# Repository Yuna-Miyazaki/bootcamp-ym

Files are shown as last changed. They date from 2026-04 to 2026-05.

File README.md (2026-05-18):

# 猫型ラジコンロボット
制作時にファイルを整理できていないため、動かない場合はバージョンが古い可能性有り。後々整えて上げ直す予定。
それと、まだ上がっていないものもあるので、上げる。

## 成果物
https://github.com/user-attachments/assets/66224314-2f7b-4e0d-81c6-8145114de999

## 使用モジュール
- M5stack capsule
- Feetech sts3215 ×3
- Feetech FE-URT-1
- M5stack UnitV2 Aiカメラ

## cat_robot
M5stack capsuleに書き込んだプログラム

### 役割
- カメラによる物体認識
- モーター制御
- HTTPサーバとして移動コマンドを受信
- 音声出力

## Joycon
ファイル名はジョイコンだが、ジョイコンではない
### 役割
- マイコンに移動コマンドを送信

## cad_work
### 制作したもの
- 車輪
- 土台
- 猫の外装
- 尻尾

## 日報
作業日の記録

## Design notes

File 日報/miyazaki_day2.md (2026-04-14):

# 日報 (宮崎)

## 作りたいもの
　ゴミを見つけたら可愛く教えてくれる猫ちゃんロボット
## 要件
- 車輪4つで動く
- 尻尾も動く(ex)
- カメラで前方情報を取得する
- 前方の物体との距離を測る(追加:近い時にカメラを起動した方が処理負荷が少なそう)

## 今日借りたもの
1. ATOMIC Motionベース (STM32F030) 1こ
    4channelサーボ制御
    2channelDCモーター制御
    取り外し可能リチウムイオンバッテリー
    背面マグネット付き
    種電源用のスライドスイッチ搭載

2. DCギアードモーター 6V 1:20 2こ
     https://akizukidenshi.com/catalog/g/g130983/
3. Motor2040 RP2040搭載 4chモーターコントローラー 1こ
    マイコン搭載のモータドライバなので使いたい
    2×デュアルHブリッジモータードライバ
    C++/MicroPythonライブラリ有り
4. FEETECH サーボ用インタフェースボード FE-URT-1 1こ
    SMSシリーズ、SCSシリーズ用インタフェースボード
    FEETECH社のやつしか無理そう

5. FEETECHシリアルバスサーボ　STS3215 2こ

## これから使う予定のもの
1. DCギアードモーター(移動用) 2つ
2. Motor2040 1つ
3. Feetechシリアルバスサーボ(尻尾用) １つ
4. Feetech サーボ用インタフェースボード FE-URT-1 1つ

 dcギアードモーター -- motor2040 -- dcギアードモーター

                        |
                        |

          feetechサーボ用インタフェースボード

                        |
                        |

              feetechシリアルバスサーボ

## 相談後
私：ギアードモーターの方が力が強いらしい
▶︎この製品のトルク欄見るとサーボの方が強い。あと配線が楽。数珠繋ぎに繋げて制御できるから便利。

1. Feetechシリアルバスサーボ 3つ(移動用、尻尾用))
2. Feetech サーボ用インタフェースボード FE-URT-1 1つ
3. esp32-s3 1つ
4. M5Stack UnitV2 AIカメラ SSD202D
5. ATOMIC Motionベース (STM32F030) 1こ

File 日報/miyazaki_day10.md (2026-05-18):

# 日報　(宮崎)

## 本日の目標
1. 尻尾動かす
2. 猫印刷する
3. 鳴き声出す

## 進捗
1. 猫印刷3分の1終わった
2. 猫の鳴き声が出た
   - フリーの猫の鳴き声ファイル拾ってくる
   - ffmpeg -i cat1.mp3 -ac 1 -ar 16000 -f u8 cat.rawで、音声ファイルをrawファイルにする
   - xxd -i cat.raw > cat_audio.hでrawファイルをヘッダファイルにする
   - ヘッダファイル参照して終わり
3. 尻尾動いた
   - たまにもげる
4. 全体通しで動いた

## 明日やること
1. 猫印刷終わらせて組み立てる
2. 動きを確認する

### atom s3
+ [x] モータ動かす
+ [x] スマホからwifi経由で命令を受け取る
+ [x] 鳴き声を出す
+ [x] カメラからゴミ判定を受け取る
+ [x] ゴミを分別する
     - bottleだったらにゃーんって出力するようにした
+ [x] 尻尾動かす

### unitV2
+ [x] 画像を取得する
+ [x] ゴミ判定をatomに送る
+ [x] ゴミ判定をする()

### 外装
+ [x] cadでタイヤ作る
+ [x] カメラや尻尾をどう取り付けるか考える
+ [x] cadで猫作る
+ [x] cadでしっぽ作る
+ [x] タイヤ印刷する
+ [ ] 猫印刷する
+ [x] 尻尾印刷する
+ [x]土台を印刷する
+ [x]土台を組み立てる
+ [x]尻尾込みで組み立てる
+ [ ]全体を組み立てる

### スマホ
+ [x] リモコンアプリの試作を作る
+ [x] リモコンアプリからモーターを前進させる
+ [x] 左右に曲がるようにする
+ [ ] モーターを、ボタンを押している間動くようにする
+ [x] 前後左右に動くようにする

### ex
+ [ ] ジョイコンにする
+ [ ] プログラムをオブジェクト指向に整える
+ [ ] リモコンアプリのUIを改良する
+ [ ] 首が動くようにする（バネ？）
+ [ ] 中身を固定するものを3Dプリンターで作って設置する

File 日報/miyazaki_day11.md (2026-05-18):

# 日報　(宮崎)

## 本日の目標
1. 猫印刷終わらせて組み立てる
2. 動きを確認する

## 進捗
1. 猫印刷終わった。
    - 胴体の前の部分がタイヤの動きを邪魔するかもしれない
    - カメラは一応はまった。
2. 移動時のモーターが、ボタンを押している間動くように変更した
3. タイヤのサイズ変更した
    - 両側から0.5mmずつ(合計1mm)縮めた 
    - 印刷した

## 明日やること

### atom s3
+ [x] モータ動かす
+ [x] スマホからwifi経由で命令を受け取る
+ [x] 鳴き声を出す
+ [x] カメラからゴミ判定を受け取る
+ [x] ゴミを分別する
     - bottleだったらにゃーんって出力するようにした
+ [x] 尻尾動かす

### unitV2
+ [x] 画像を取得する
+ [x] ゴミ判定をatomに送る
+ [x] ゴミ判定をする()

### 外装
+ [x] cadでタイヤ作る
+ [x] カメラや尻尾をどう取り付けるか考える
+ [x] cadで猫作る
+ [x] cadでしっぽ作る
+ [x] タイヤ印刷する
+ [x] 猫印刷する
+ [x] 尻尾印刷する
+ [x] 土台を印刷する
+ [x] 土台を組み立てる
+ [x] 尻尾込みで組み立てる
+ [ ] 全体を組み立てる
+ [ ] 台車と猫を固定する部品を作ってボンドでつける

### スマホ
+ [x] リモコンアプリの試作を作る
+ [x] リモコンアプリからモーターを前進させる
+ [x] 左右に曲がるようにする
+ [x] モーターを、ボタンを押している間動くようにする
+ [x] 前後左右に動くようにする

### ex
+ [ ] ジョイコンにする
+ [ ] プログラムをオブジェクト指向に整える
+ [ ] リモコンアプリのUIを改良する
+ [ ] 首が動くようにする（バネ？）
+ [ ] 芸を覚えさせるコマンドとか欲しい

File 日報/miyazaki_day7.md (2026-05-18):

# 日報　(宮崎)

## 本日の目標
1. 土台を作る

##　進捗
1. 土台を作った
   - freecadがわかりにくかったので、fusionをインストールした。(educationプランだと無料)
   - 形を作って3dプリンターで印刷した

## 明日やること
1. 土台とモーターを組み立てる
2. 組み立てたものがちゃんと走るか確かめる
3. 猫の形を考える

## やることリスト
## やることリスト
### atom s3
+ [x] モータ動かす
+ [x] スマホからwifi経由で命令を受け取る
+ [ ] 鳴き声を出す
+ [x] カメラからゴミ判定を受け取る
+ [x] ゴミを分別する(bottleだったらフラグonみたいにする)
     - bottleだったらにゃーんって出力するようにした

### unitV2
+ [x] 画像を取得する
+ [x] ゴミ判定をatomに送る
+ [x] ゴミ判定をする()

### 外装
+ [x] cadでタイヤ作る
+ [ ] cadで猫作る
+ [ ] cadでしっぽ作る
+ [x] タイヤ印刷する
+ [ ] 猫印刷する
+ [ ] 尻尾印刷する
+ [x]土台を印刷する
+ [ ]土台を組み立てる

### スマホ
+ [x] リモコンアプリの試作を作る
+ [x] リモコンアプリからモーターを前進させる
+ [x] 左右に曲がるようにする
+ [ ] モーターを、ボタンを押している間動くようにする
+ [x] 前後左右に動くようにする
+ [ ] ジョイコンにする

### ex
+ [ ] プログラムをオブジェクト指向に整える

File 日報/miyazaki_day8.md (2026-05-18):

# 日報　(宮崎)

## 本日の目標
1. 土台とモーターを組み立てる
2. 組み立てたものがちゃんと走るか確かめる
3. 猫の形を考える

## 進捗
1. 土台とモーターを組み立てた
   - 土台にモーターを取り付けて安定電源繋いで走らせた
   - モバイルバッテリーのみで走らせた

## 明日やること
1. 尻尾作って印刷する。
2. 猫作る

## やることリスト
### atom s3
+ [x] モータ動かす
+ [x] スマホからwifi経由で命令を受け取る
+ [ ] 鳴き声を出す
+ [x] カメラからゴミ判定を受け取る
+ [x] ゴミを分別する(bottleだったらフラグonみたいにする)
     - bottleだったらにゃーんって出力するようにした

### unitV2
+ [x] 画像を取得する
+ [x] ゴミ判定をatomに送る
+ [x] ゴミ判定をする()

### 外装
+ [x] cadでタイヤ作る
+ [ ] カメラや尻尾をどう取り付けるか考える
+ [ ] cadで猫作る
+ [x] cadでしっぽ作る
+ [x] タイヤ印刷する
+ [ ] 猫印刷する
+ [ ] 尻尾印刷する
+ [x]土台を印刷する
+ [x]土台を組み立てる

### スマホ
+ [x] リモコンアプリの試作を作る
+ [x] リモコンアプリからモーターを前進させる
+ [x] 左右に曲がるようにする
+ [ ] モーターを、ボタンを押している間動くようにする
+ [x] 前後左右に動くようにする
+ [ ] ジョイコンにする

### ex
+ [ ] プログラムをオブジェクト指向に整える
+ [ ] リモコンアプリのUIを改良する

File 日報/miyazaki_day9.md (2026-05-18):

# 日報　(宮崎)

## 本日の目標
1. 尻尾作って印刷する。
2. 猫作る

## 進捗
1. 尻尾印刷できた
   - まだ動かしていない
2. 猫の形だけつくった
   - デカすぎて分割しないと印刷できない

## 明日やること
1. 尻尾動かす
2. 猫印刷する
3. 鳴き声出す

### atom s3
+ [x] モータ動かす
+ [x] スマホからwifi経由で命令を受け取る
+ [ ] 鳴き声を出す
+ [x] カメラからゴミ判定を受け取る
+ [x] ゴミを分別する(bottleだったらフラグonみたいにする)
     - bottleだったらにゃーんって出力するようにした

### unitV2
+ [x] 画像を取得する
+ [x] ゴミ判定をatomに送る
+ [x] ゴミ判定をする()

### 外装
+ [x] cadでタイヤ作る
+ [x] カメラや尻尾をどう取り付けるか考える
+ [x] cadで猫作る
+ [x] cadでしっぽ作る
+ [x] タイヤ印刷する
+ [ ] 猫印刷する
+ [x] 尻尾印刷する
+ [x]土台を印刷する
+ [x]土台を組み立てる
+ [ ]尻尾込みで組み立てる

### スマホ
+ [x] リモコンアプリの試作を作る
+ [x] リモコンアプリからモーターを前進させる
+ [x] 左右に曲がるようにする
+ [ ] モーターを、ボタンを押している間動くようにする
+ [x] 前後左右に動くようにする
+ [ ] ジョイコンにする

### ex
+ [ ] プログラムをオブジェクト指向に整える
+ [ ] リモコンアプリのUIを改良する

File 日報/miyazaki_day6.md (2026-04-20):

# 日報　(宮崎)

## 本日の目標
1. 車輪動かすコードとカメラから出力を受け取るコードを合体させる

## 進捗
1. 車輪動かすコードとカメラから出力を受け取るコードを合体させた
   - 今のままだと拡張や修正がしにくいので、余裕がある時にオブジェクト指向に準拠した構造に作り直したい

2. 左回転、右回転、後方移動、停止を追加した

## 学び
1. パスワードなどの機密情報をgithubにあげるときは、secret.hなどにパスワードを入れて使うときに読み込むようにする。んでsecret.hをgitignoreに追加する。
2. 開発中のものはdevブランチ、完璧に動くものはmainブランチにプッシュする。

## 明日やること
1. 部品を入れる箱の形を考える
2. 実際に動かすときの形に組み立てる
3. 猫の形を考える
4. 

## やることリスト
### atom s3
+ [x] モータ動かす
+ [x] スマホからwifi経由で命令を受け取る
+ [ ] 鳴き声を出す
+ [x] カメラからゴミ判定を受け取る
+ [x] ゴミを分別する(bottleだったらフラグonみたいにする)
     - bottleだったらにゃーんって出力するようにした

### unitV2
+ [x] 画像を取得する
+ [x] ゴミ判定をatomに送る
+ [x] ゴミ判定をする()

### 外装
+ [x] cadでタイヤ作る
+ [ ] cadで猫作る
+ [ ] cadでしっぽ作る
+ [ ] cadでキャスター作る
+ [x] タイヤ印刷する
+ [ ] 猫印刷する
+ [ ] 尻尾印刷する
+ [ ] キャスター印刷する

### スマホ
+ [x] リモコンアプリの試作を作る
+ [x] リモコンアプリからモーターを前進させる
+ [x] 左右に曲がるようにする
+ [ ] モーターを押している間動くようにする
+ [x] 前後左右に動くようにする
+ [ ] ジョイコンにする

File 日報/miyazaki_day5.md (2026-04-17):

# 日報　(宮崎)

## 本日の目標
1. unitV2からATOM S3にゴミ落ちてたよフラグ送れるか確認する
2. 画像取得からゴミ認識までできるやつがあるかUnitV2の情報を調べる

## 進捗
1. スマホでモーター制御できた
   - iphoneのテザリング繋げてatom s3のipアドレス取得した
   - swiftでhttpリクエストおくるコード作った
   - 前進、停止のボタンは作ったので、次は前後左右にボタンを押している間動き続けるようにする

2. UnitV2から物体認識時のメッセージを受け取れた
3. ゴミ認識できるものに関しては

## バカくそ詰まってたこと
1. UnitV2の使い方
   - そもそも何をどうやったら認識結果が受け取れるのかとかがわからない
   - とりあえずドライバ入れようとしたら安全が保証できないからって却下された▶︎プライバシーとセキュリティのとこ触ったら入った
   - 物体認識をやらせようとした時、unitV2さんはシリアル出力かなんかで認識結果だけ送ってくれるみたいだから、それをATOM S3で受け取ろうとした
   - なんか色々触ってたら一生再起動っぽいことしてるのが表示される
   - カメラから何もこない。何をしなければならないのかもわからない
         entry 0x403c98d0
         ESP-ROM:esp32s3-20210327
         Build:Mar 27 2021
         rst:0x8 (TG1WDT_SYS_RST),boot:0x2b (SPI_FAST_FLASH_BOOT)
         Saved PC:0x403743c5
         SPIWP:0xee
         mode:DIO, clock div:1
         load:0x3fce3808,len:0x4bc
         load:0x403c9700,len:0xbd8
         load:0x403cc700,len:0x2a0c
         entry 0x403c98d0
         ESP-ROM:esp32s3-20210327
         Build:Mar 27 2021
         rst:0x8 (TG1WDT_SYS_RST),boot:0x2b (SPI_FAST_FLASH_BOOT)
         Saved PC:0x40379008
         SPIWP:0xee
         mode:DIO, clock div:1
         load:0x3fce3808,len:0x4bc
         load:0x403c9700,len:0xbd8
         load:0x403cc700,len:0x2a0c
         .......て感じ
   - RxピンとTxピンが間違ってたからかな？そこ直したら出なくなった
   -   // JSONコマンド送信
        Serial2.println("{\"function\":\"Object Recognition\",\"args\":[\"nanodet_80class\"]}"); で物体認識モードに切り替えて、
        if (Serial2.available()) {
            Serial.println(Serial2.readStringUntil('\n'));
        }でカメラからのメッセージをatoms3で受け取れた
2. 

## 明日やること
1. 車輪動かすコードとカメラから出力を受け取るコードを合体させる
2. 

## やることリスト
### atom s3
+ [x] モータ動かす
+ [x] スマホからwifi経由で命令を受け取る
+ [ ] 鳴き声を出す
+ [x] カメラからゴミ判定を受け取る
+ [ ] ゴミを分別する(bottleだったらフラグonみたいにする)

### unitV2
+ [x] 画像を取得する
+ [x] ゴミ判定をatomに送る
+ [x] ゴミ判定をする()

### 外装
+ [x] cadでタイヤ作る
+ [ ] cadで猫作る
+ [ ] cadでしっぽ作る
+ [ ] cadでキャスター作る
+ [x] タイヤ印刷する
+ [ ] 猫印刷する
+ [ ] 尻尾印刷する
+ [ ] キャスター印刷する

### スマホ
+ [x] リモコンアプリの試作を作る
+ [x] リモコンアプリからモーターを前進させる
+ [ ] モーターを押している間動くようにする
+ [ ] 前後左右に動くようにする
+ [ ] ジョイコンにする

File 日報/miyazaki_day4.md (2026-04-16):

# 日報　(宮崎)

## 本日の目標
1. UIfrow2でカメラ画像を取得する

## 進捗
1. 車輪の試作ができた(cad)
    FreeCADを使った
    使う時に見た説明：
    - [freecadの使い方説明してくれてるやつ](https://www.kobe-kosen.ac.jp/~waseda/upgradeyourlife/m2/2023-freecad020_cad-stl.pdf)
    - [穴開ける方法教えてくれるやつ](https://snobotech.com/pocket)
    - 保存 + exportで拡張子がstepのやつも保存する

2. カメラが起動した
   - 接続タイムアウトがたまに発生する
   - カクカクするけどちゃんと映る。ラグがすっごい

3. カメラに接続してpythonで画像を保存できた
   - sudo入れないと権限がなくて実行できないので他の方法があったら他の方法の方が良さそう
   - 他にもいいやり方がありそう
   - 連続でずっと画像を取得するコード作った

4. ATOM S3をwifiに接続してIPアドレスを取得した(mm2020)

5. 車輪を3dプリンタで印刷した
   - bambu studioインストールした

## やることリスト
### atom s3
+ [x] モータ動かす
+ [ ] スマホからwifi経由で命令を受け取る
+ [ ] 鳴き声を出す
+ [ ] カメラからゴミ判定を受け取る

### unitV2
+ [x] 画像を取得する
+ [ ] ゴミ判定をatomに送る
+ [ ] ゴミ判定をする

### 外装
+ [x] cadでタイヤ作る
+ [ ] cadで猫作る
+ [ ] cadでしっぽ作る
+ [ ] cadでキャスター作る
+ [x] タイヤ印刷する
+ [ ] 猫印刷する
+ [ ] 尻尾印刷する
+ [ ] キャスター印刷する

### スマホ
+ [ ] リモコンアプリ作る

## 明日やること
1. unitV2からATOM S3にゴミ落ちてたよフラグ送れるか確認する
2. 画像取得からゴミ認識までできるやつがあるかUnitV2の情報を調べる

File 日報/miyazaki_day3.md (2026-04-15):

# 日報　(宮崎)

## 本日の目標
1. atomic s3 dev kitの動作確認をする
2. どういう動きでもいいからとにかくサーボモーターを動かしてみる
3. カメラからデータが取得できることを確認する

## 進捗
 1. atomic s3 dev kitのモニターに文字列を表示した
 2. サーボモーター動いた
 3. 安定化電源の使い方を知った
    - ▶︎で on/of
 4. 

## 詰まった点
### モーターが動かない
- usb-typebにモバイルバッテリーを繋いだ
    - ボードは光ったけどモーターは動かなかった
    - 良くないやり方らしいのでやらない
      - モーターのノイズで電源にバカでか電圧がかかったりするから、マイコンと同じ電源は使わないらしい。モータ動かす電源と、通信する電源は別にしてるらしい。 
- モーターの通信速度が100000なのに115200で動かそうとしてた
- RXとTXの繋ぎ方が逆になってる説あった
    - 逆にしても動かなかったのでこれじゃない 
- SCServoのライブラリとってくるとこをミスってた
    - workloads/SCServoにしたらモーター動いた 

## 明日やること
- UIfrow2でカメラ画像を取得する

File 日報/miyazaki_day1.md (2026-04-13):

# 日報 (宮崎)

## 今日やったこと

1. Antigravityのインストール
2. githubのeducationアカウントの作成
3. リポジトリの作成
4. githubの使い方
   - add: control+sみたいなの
   - push: 差分をリモートに反映
   - pull: リモートの差分をローカルに反映
   - comit: 変更をローカルリポジトリに反映
   - clone: リモートをローカルにコピー
3. Markdown記法の学習

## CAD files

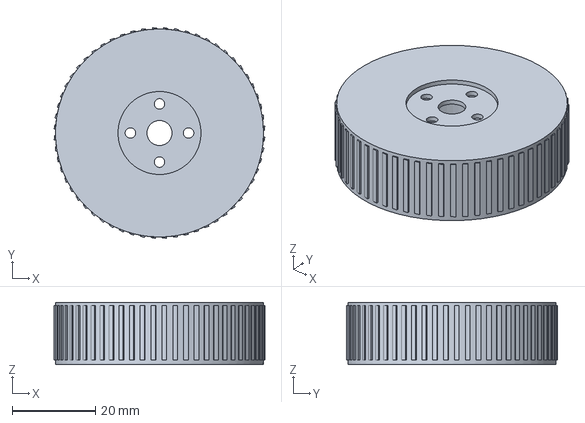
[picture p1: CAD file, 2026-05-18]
cadwork/whoile.FCStd
50.7 x 50.7 x 15.0 mm

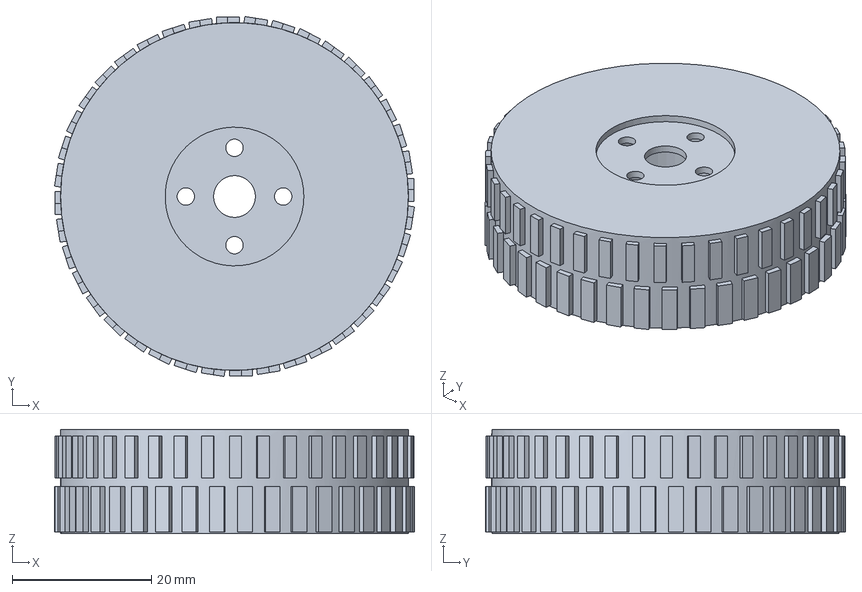
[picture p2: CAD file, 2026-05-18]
cadwork/whoile2.FCStd
51.8 x 51.8 x 15.0 mm

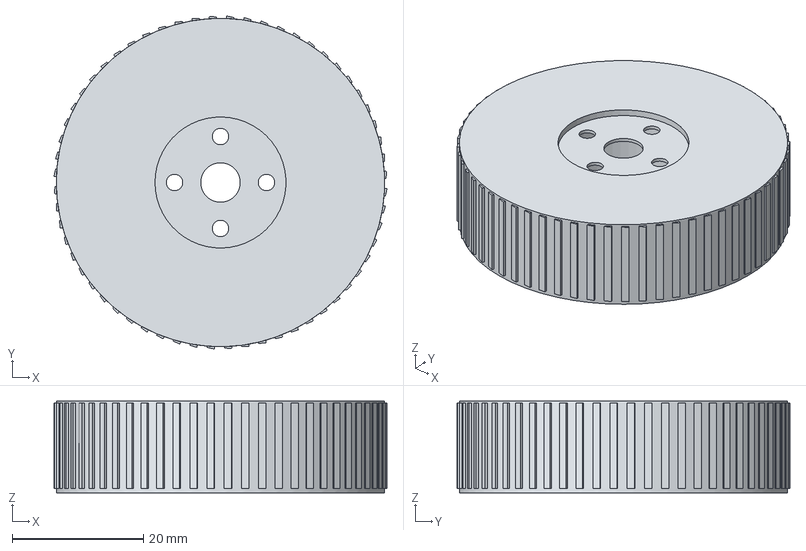
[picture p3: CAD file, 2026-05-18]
cadwork/whoile-Body_resize-1mm.step
50.7 x 50.7 x 14.0 mm

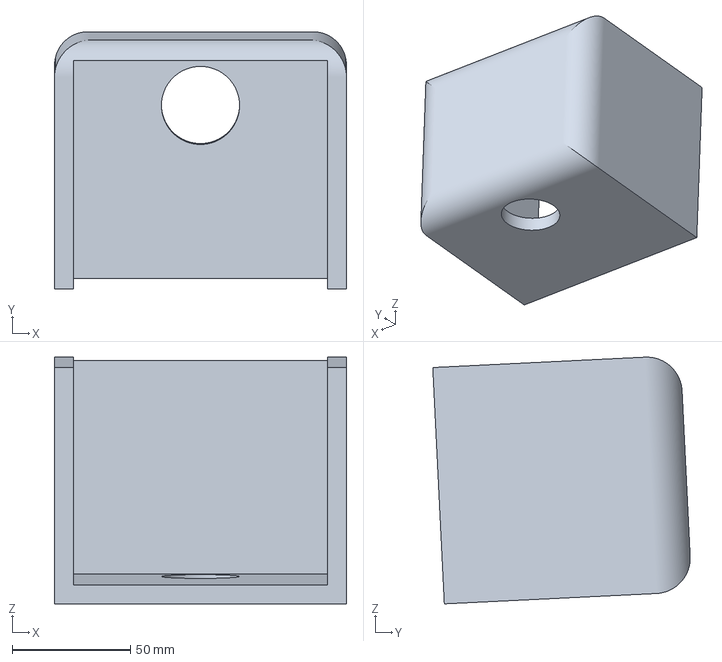
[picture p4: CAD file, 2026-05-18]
cadwork/Neko_Under_back.3mf
123.4 x 108.8 x 104.3 mm

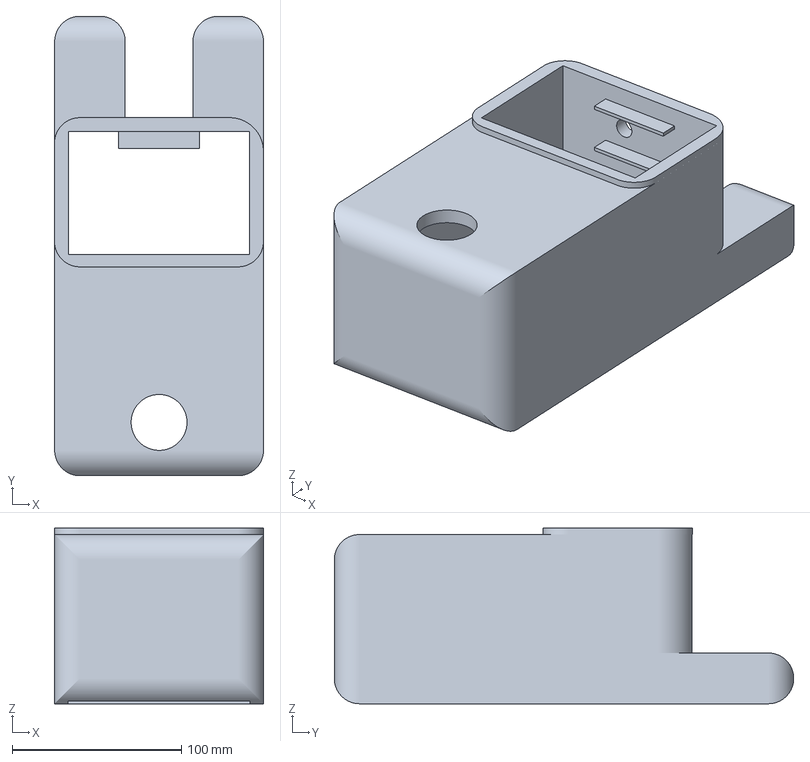
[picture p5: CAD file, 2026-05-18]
cadwork/Neko_Under.3mf
123.5 x 271.5 x 103.7 mm

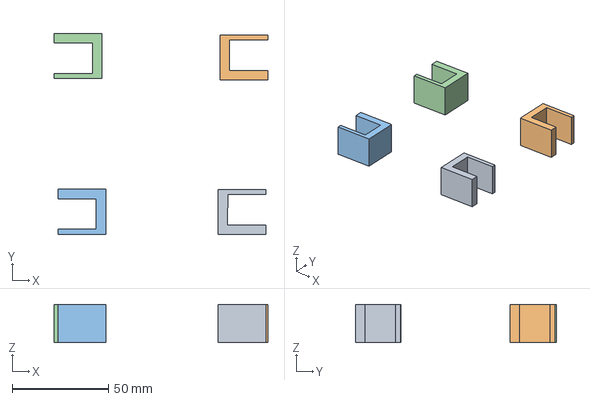
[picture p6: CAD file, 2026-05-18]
cadwork/surporter2.3mf
111.4 x 104.9 x 20.0 mm
surporter.step x 4

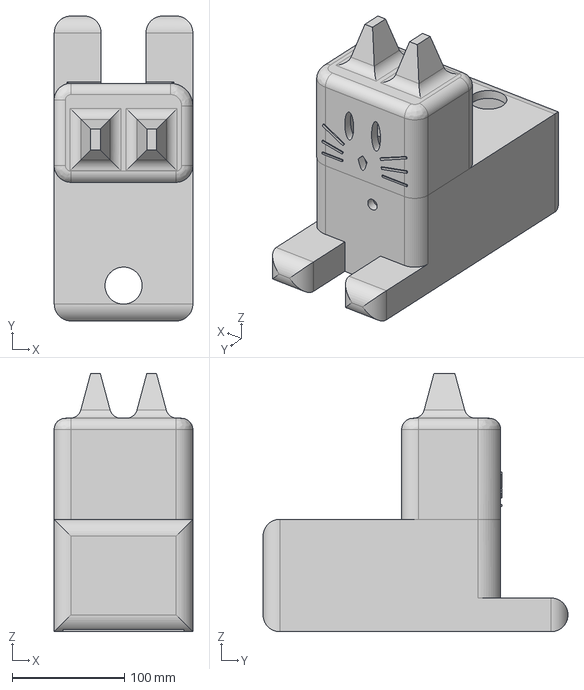
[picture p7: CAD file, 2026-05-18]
cadwork/Neko_ver1.step
123.5 x 271.5 x 230.0 mm

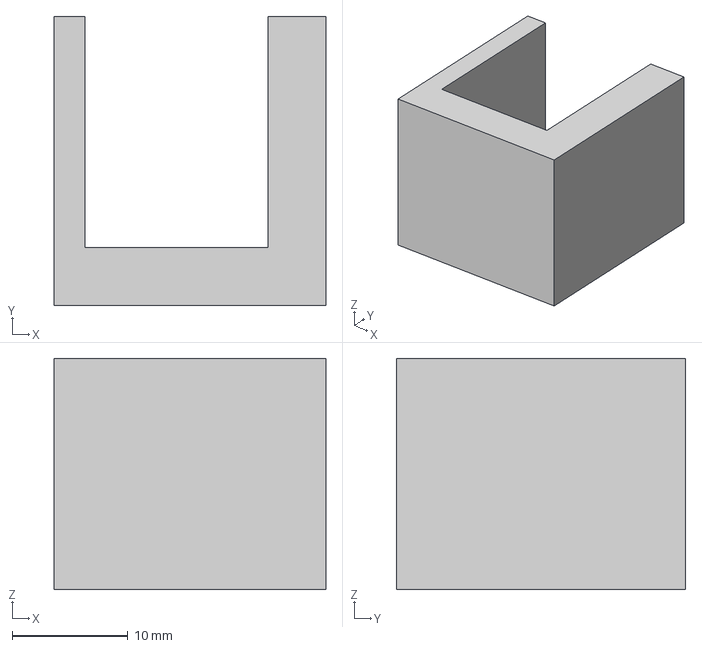
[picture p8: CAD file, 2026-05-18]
cadwork/surporter.step
23.5 x 25.0 x 20.0 mm

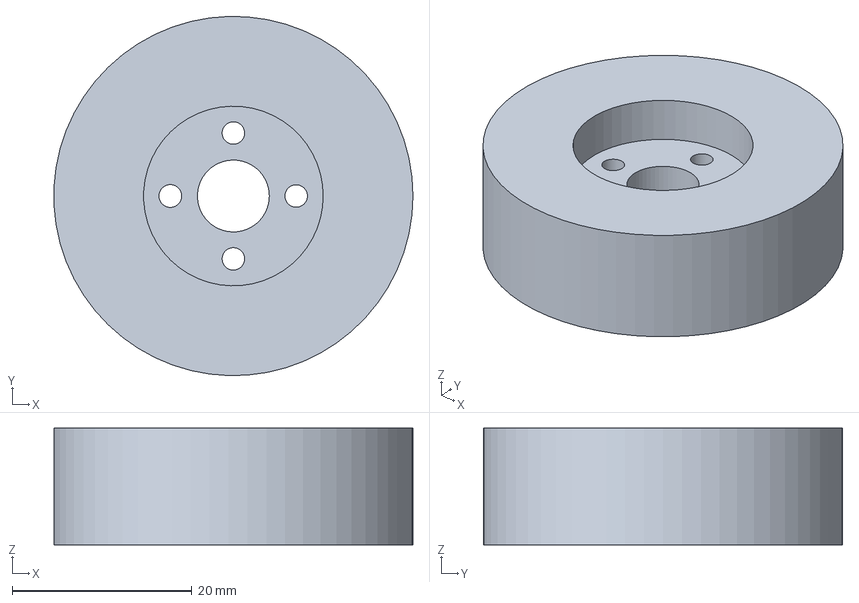
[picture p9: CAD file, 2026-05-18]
cadwork/taiya.FCStd
40.0 x 40.0 x 13.0 mm

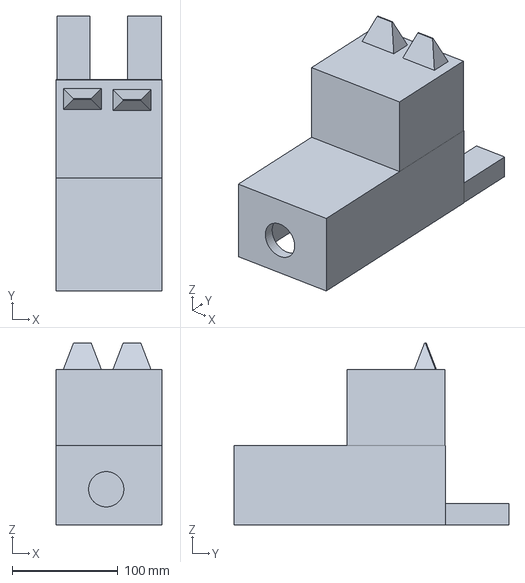
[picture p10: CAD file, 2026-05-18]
cadwork/Cat1.FCStd
100.0 x 260.0 x 172.0 mm

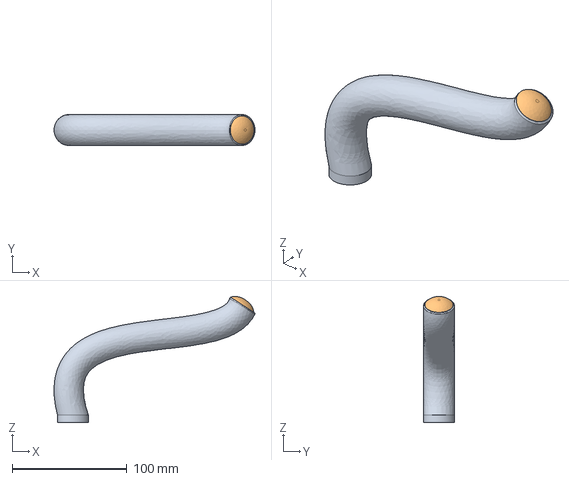
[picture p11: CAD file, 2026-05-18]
cadwork/cat_tail.step
175.0 x 27.0 x 109.7 mm

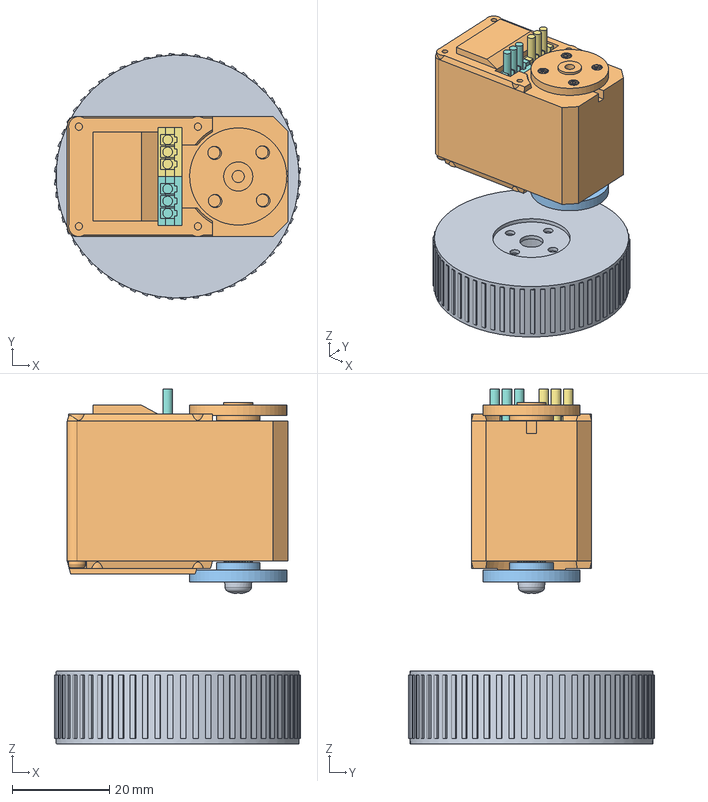
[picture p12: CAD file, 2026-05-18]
cadwork/車輪.FCStd
50.7 x 50.7 x 73.1 mm
Composant2
Composant3
Composant4
vis
vis001
connector F
connector F001
Vis \X\E0 t\X\EAte tronconique JIS B 1111 - M3 x 4 - H Acier inoxydable A2 Standard v1

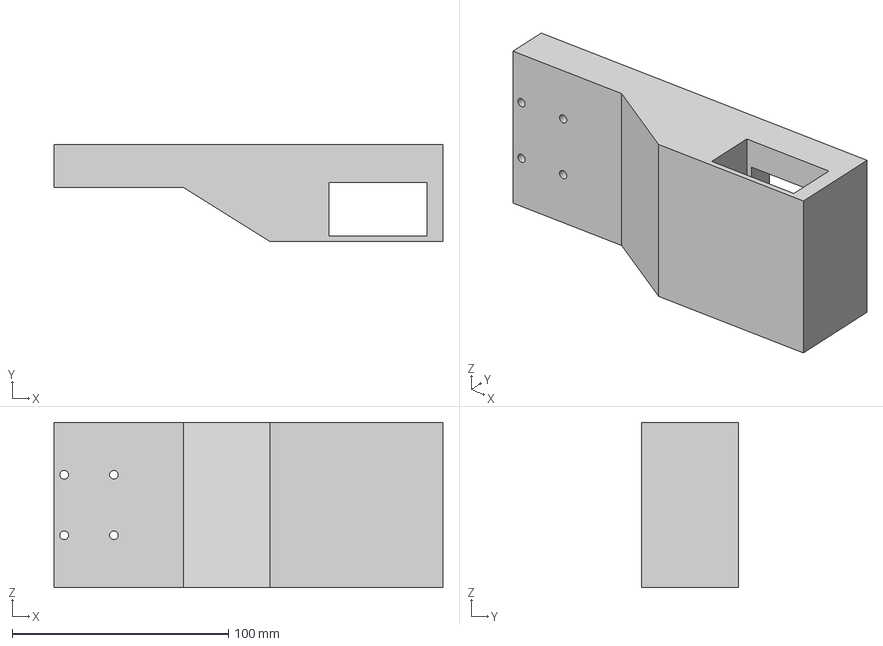
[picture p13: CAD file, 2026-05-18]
cadwork/car_body.step
180.0 x 45.0 x 76.4 mm

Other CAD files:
cadwork/Neko_Under_front.gcode.3mf
cadwork/surporters.gcode.3mf
cadwork/cat_tail2.gcode.3mf
cadwork/Neko_Under_back.gcode.3mf
cadwork/whoile-Body.step
cadwork/Neko_Head.3mf
cadwork/Neko_Under_front.3mf
cadwork/Neko_ver1.3mf
cadwork/Neko_ver1.stl
cadwork/car_body.3mf
cadwork/cat_tail.3mf
cadwork/cat_tail.gcode.3mf
cadwork/surporter.3mf
cadwork/surporter2.gcode.3mf
cadwork/testcat.FCStd
cadwork/whoile-Body.3mf
cadwork/whoile-Body_resize-1mm.3mf
cadwork/whoileBody_resized-1mm.gcode.3mf
cadwork/whoileOrigin.FCStd
cadwork/ホイール例.FCStd

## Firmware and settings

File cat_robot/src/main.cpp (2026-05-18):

// #include "M5Capsule.h"
#include "cat_audio.h"
#include <Arduino.h>
#include <M5Unified.h>
#include <SCServo.h>
#include <WebServer.h>
#include <WiFi.h>

// ===== WiFi =====
const char *ssid = "***";
const char *password = "***";

// ===== Web =====
WebServer server(80);

// ===== Servo =====
SMS_STS st;
HardwareSerial servoSerial(1);

// ===== UART UnitV2 =====
HardwareSerial camSerial(2);

// ===== モード =====
enum Mode { STOP, FORWARD, BACKWARD, TURNRIGHT, TURNLEFT };
Mode mode = STOP;

// ===== スピード =====
int speedVal = 50;

// ===== 尻尾サーボ =====
constexpr uint8_t SERVO_ID = 4;
constexpr int SERVO_SPEED = 800;
constexpr int SERVO_ACC = 50;

constexpr int CENTER_POS = 2048;
constexpr int LEFT_90_POS = CENTER_POS - 1024;
constexpr int RIGHT_90_POS = CENTER_POS + 1024;

// ===== 尻尾タイマー =====
unsigned long lastTailMoveTime = 0;
bool tailLeft = true;
constexpr unsigned long TAIL_INTERVAL = 200;

// ===== 音声 =====
void meow() {
  M5.Speaker.setVolume(255);
  M5.Speaker.playRaw(cat_raw, cat_raw_len, 16000, false, 1, -1, true);

  while (M5.Speaker.isPlaying()) {
    server.handleClient(); // 鳴いてる間もスマホ操作を受ける
    delay(1);
  }

  M5.Speaker.stop();
}

// ===== 尻尾動作 =====
void moveServoCenter() {
  st.WritePosEx(SERVO_ID, CENTER_POS, SERVO_SPEED, SERVO_ACC);
}

void moveServoleft() {
  st.WritePosEx(SERVO_ID, LEFT_90_POS, SERVO_SPEED, SERVO_ACC);
}

void moveServoright() {
  st.WritePosEx(SERVO_ID, RIGHT_90_POS, SERVO_SPEED, SERVO_ACC);
}

// ===== WiFi接続確認 =====
void connectWiFi() {
  Serial.println("Connecting WiFi...");

  M5.Display.fillScreen(TFT_BLACK);
  M5.Display.setCursor(0, 0);

  WiFi.begin(ssid, password);

  int retry = 0;

  while (WiFi.status() != WL_CONNECTED) {
    delay(500);
    Serial.print(".");

    retry++;

    if (retry > 40) {
      Serial.println("\nWiFi FAILED");

      while (true) {
        delay(1000);
      }
    }
  }

  Serial.println("\nWiFi Connected!");
  Serial.print("IP: ");
  Serial.println(WiFi.localIP());
}

// ===== WiFiハンドラ =====
void handleForward() {
  mode = FORWARD;
  Serial.println("COMMAND: FORWARD");
  server.send(200, "text/plain", "forward");
}

void handleBackward() {
  mode = BACKWARD;
  Serial.println("COMMAND: BACKWARD");
  server.send(200, "text/plain", "backward");
}

void handleStop() {
  mode = STOP;
  Serial.println("COMMAND: STOP");
  server.send(200, "text/plain", "stop");
}

void handleTurnRight() {
  mode = TURNRIGHT;
  Serial.println("COMMAND: TURN RIGHT");
  server.send(200, "text/plain", "turnright");
}

void handleTurnLeft() {
  mode = TURNLEFT;
  Serial.println("COMMAND: TURN LEFT");
  server.send(200, "text/plain", "turnleft");
}

// ===== サーボを車輪モードにする =====
void setWheelMode(int id) {
  st.unLockEprom(id);
  st.writeByte(id, 33, 1);
  st.LockEprom(id);
  delay(50);
}

// ===== モータ制御 =====
void updateMotors() {
  if (mode == FORWARD) {
    st.WriteSpe(1, -1500, speedVal);
    st.WriteSpe(2, 1500, speedVal);
  } else if (mode == BACKWARD) {
    st.WriteSpe(1, 1500, speedVal);
    st.WriteSpe(2, -1500, speedVal);
  } else if (mode == TURNRIGHT) {
    st.WriteSpe(1, -1500, speedVal);
    st.WriteSpe(2, 300, speedVal);
  } else if (mode == TURNLEFT) {
    st.WriteSpe(1, -300, speedVal);
    st.WriteSpe(2, 1500, speedVal);
  } else {
    st.WriteSpe(1, 0, 0);
    st.WriteSpe(2, 0, 0);
  }
}

// ===== 尻尾制御 =====
void updateTail() {
  if (millis() - lastTailMoveTime >= TAIL_INTERVAL) {
    lastTailMoveTime = millis();

    if (tailLeft) {
      moveServoleft();
    } else {
      moveServoright();
    }

    tailLeft = !tailLeft;
  }
}

void setup() {
  auto cfg = M5.config();
  M5.begin(cfg);
  // シリアルポートの初期化
  Serial.begin(115200);
  // アクセスポイントに接続
  connectWiFi();
  // コールバック関数の定義
  server.on("/forward", handleForward);
  server.on("/backward", handleBackward);
  server.on("/stop", handleStop);
  server.on("/turnright", handleTurnRight);
  server.on("/turnleft", handleTurnLeft);
  server.begin();

  // ===== Servo =====
  servoSerial.begin(1000000, SERIAL_8N1, 1, 3);
  st.pSerial = &servoSerial;

  setWheelMode(1);
  setWheelMode(2);

  // ===== UnitV2 UART =====
  camSerial.begin(115200, SERIAL_8N1, 15, 13);
  delay(1000);

  camSerial.println(
      "{\"function\":\"Object Recognition\",\"args\":[\"nanodet_80class\"]}");
  Serial.println("Camera: Object Recognition Mode ON");

  moveServoCenter();

  // Serial.println("SYSTEM READY");
  meow();
}

void loop() {
  server.handleClient();

  updateMotors();

  // ===== カメラ受信 =====
  if (camSerial.available()) {
    String line = camSerial.readStringUntil('\n');
    // Serial.println("[CAM] " + line);

    if (line.indexOf("\"type\":\"bottle\"") != -1) {
      meow();
    }
  }

  updateTail();

  delay(10);
}

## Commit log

2026-04-15 caddata update
    [whoile.FCStd]
2026-05-18 Update repository with current changes
    [Cat1.FCStd, Neko_Head.3mf, Neko_Under.3mf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]
